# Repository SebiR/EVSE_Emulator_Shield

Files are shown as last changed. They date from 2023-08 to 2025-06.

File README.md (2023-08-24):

# EVSE Emulator Arduino Shield
An Arduino shield to emulate an EVSE (Electric Vehicle Supply Equipment), so basically it emulates a car charger

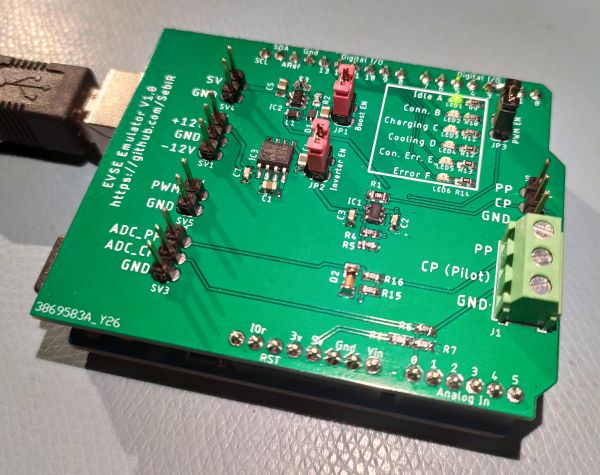
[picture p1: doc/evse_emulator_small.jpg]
EVSe Emulator Photo


## Features
* on-board charge pump and inverter for +12/-12V pilot signal
* Pilot level and PP level go to ADC channels
* Status LEDs

## Firmware
The Firmware is still in progress. It will be documented once finished

### Known Issues
* ADC values are dependent from USB voltage

## Resources
https://www.goingelectric.de/wiki/Typ2-Signalisierung-und-Steckercodierung/

## Disclaimer
This project was created to test an EV emulator. This project is not intended to be used in an actual Wallbox. 
There are no safety features and neither the firmware nor the hardware are created with robustness and safety in mind.
Although the state machine would be able to work as a full EVSE.

Use at your own risk. Im not liable for burning houses, cars or pants.

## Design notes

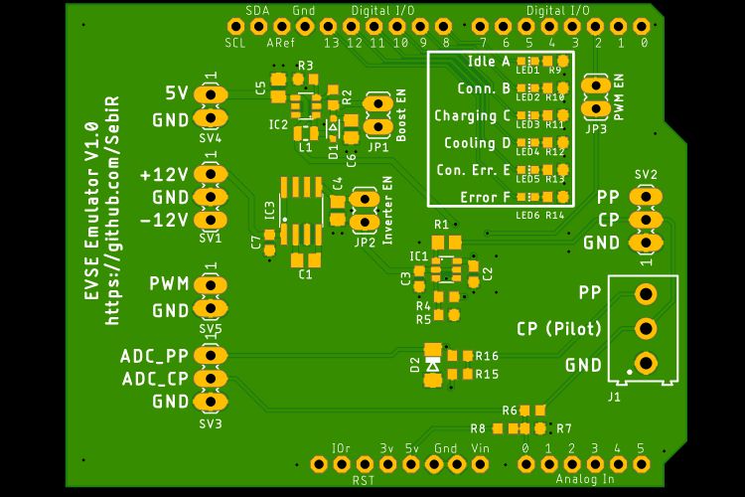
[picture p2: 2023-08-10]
doc/EVSE_Arduino_Shield_small.jpg

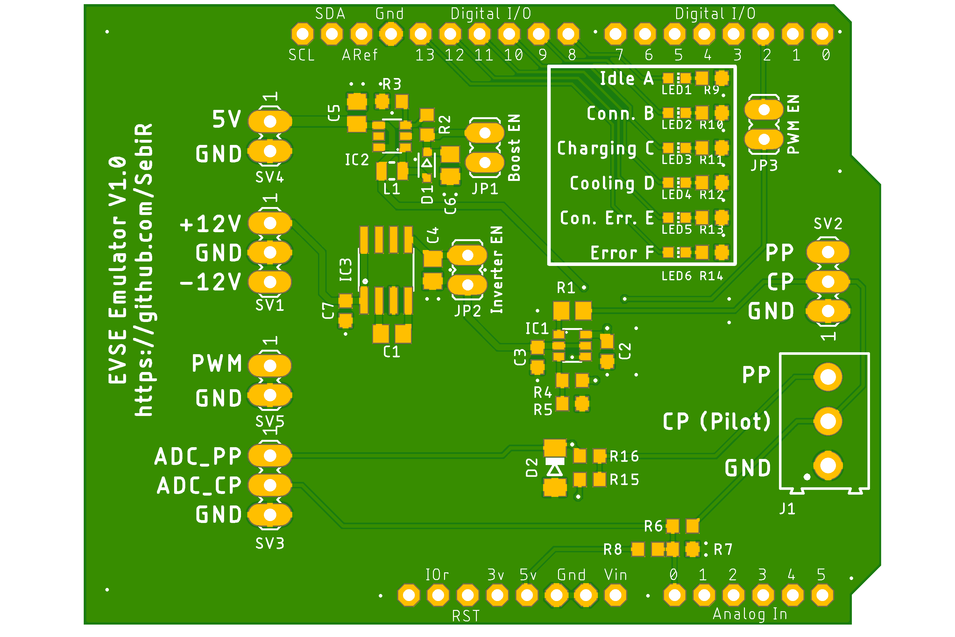
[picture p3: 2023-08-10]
doc/EVSE_Arduino_Shield.png

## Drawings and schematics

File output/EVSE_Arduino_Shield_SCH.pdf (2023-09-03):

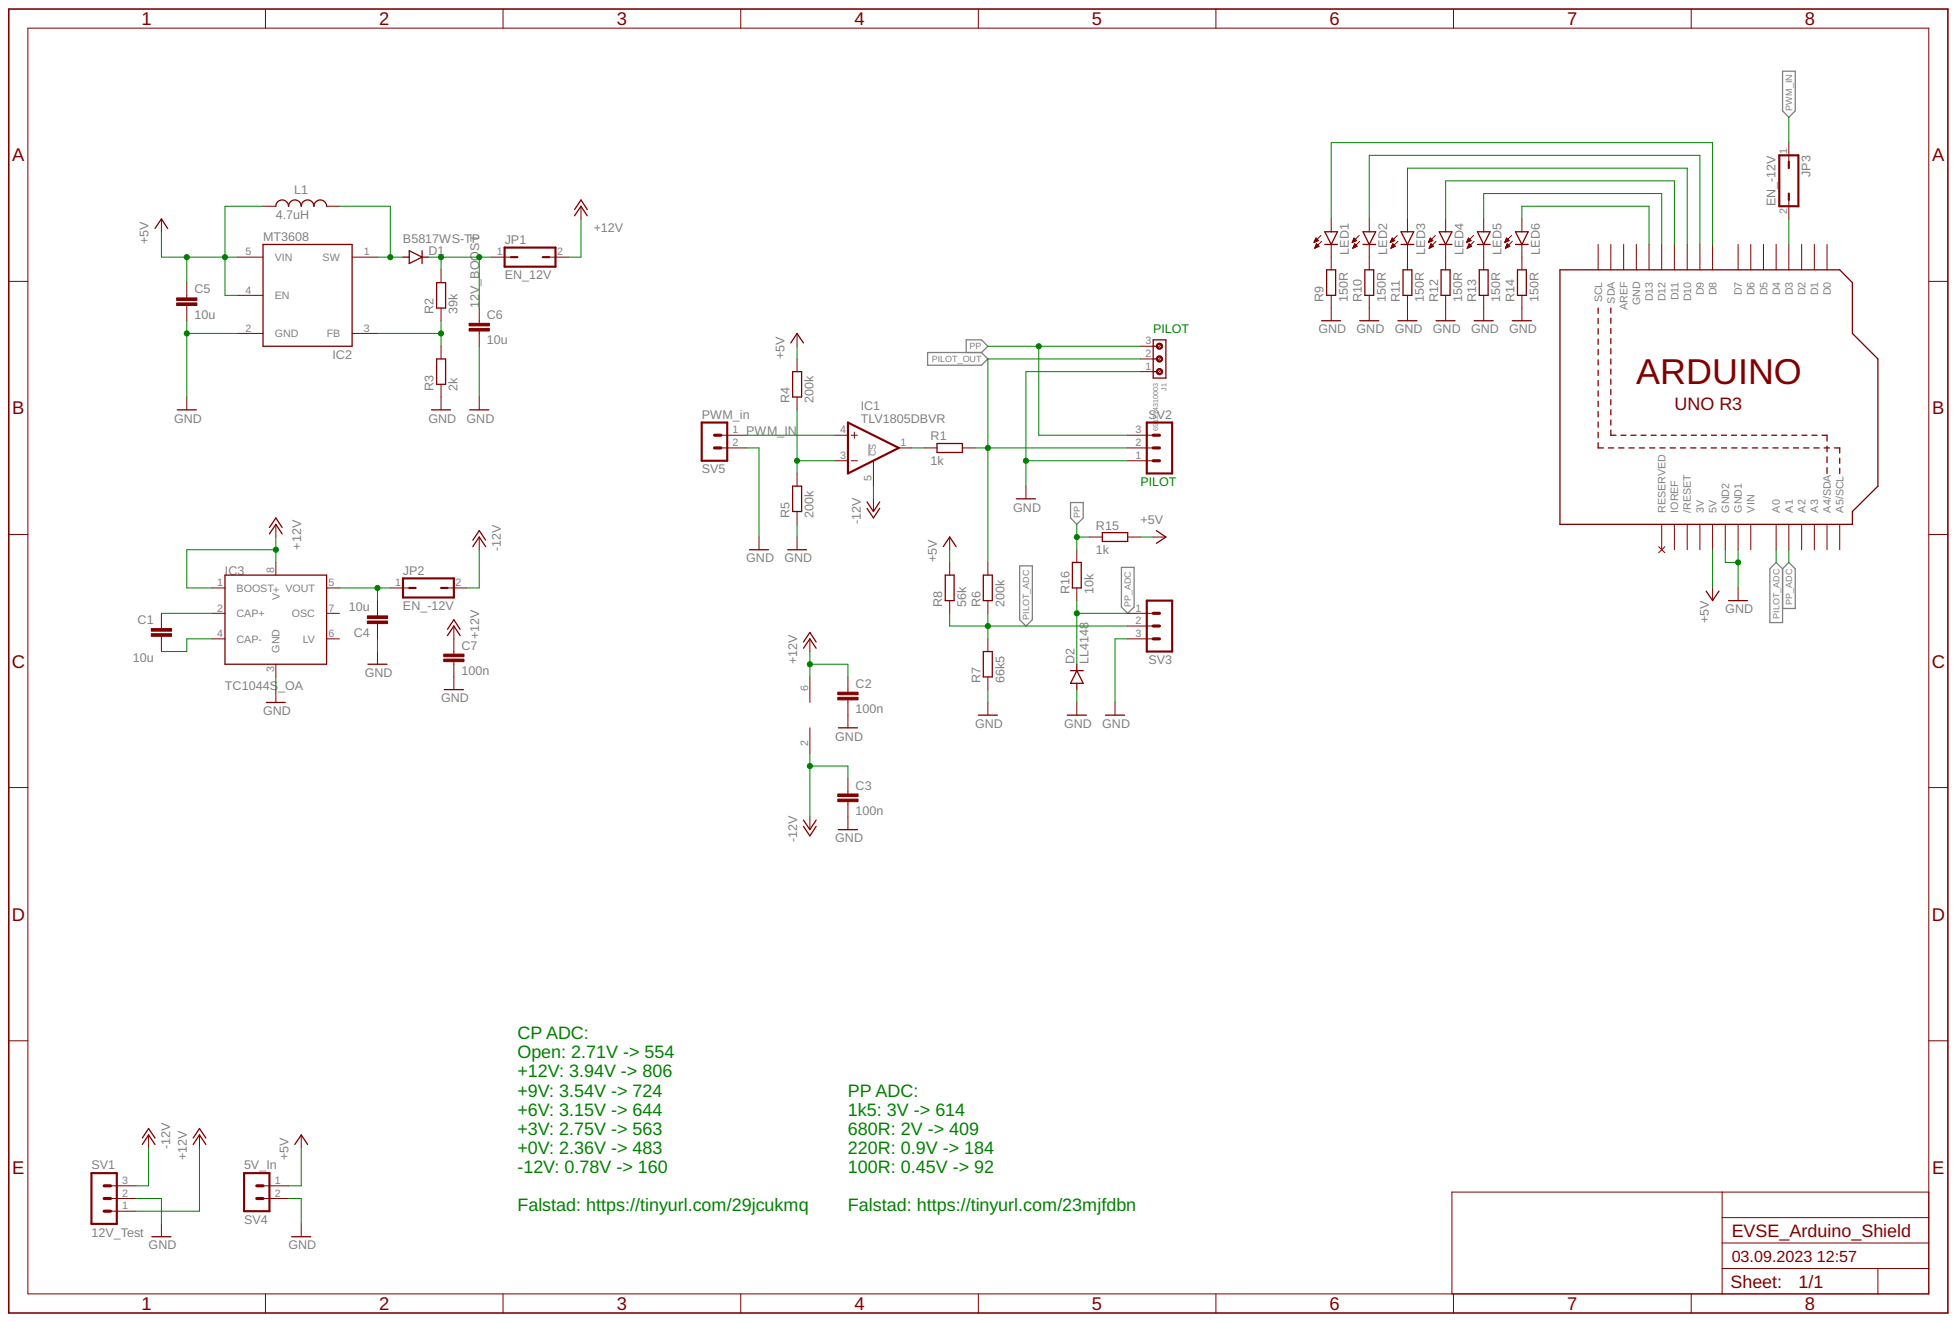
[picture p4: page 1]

GND GND GND

Falstad: https://tinyurl.com/29jcukmq

Falstad: https://tinyurl.com/23mjfdbn

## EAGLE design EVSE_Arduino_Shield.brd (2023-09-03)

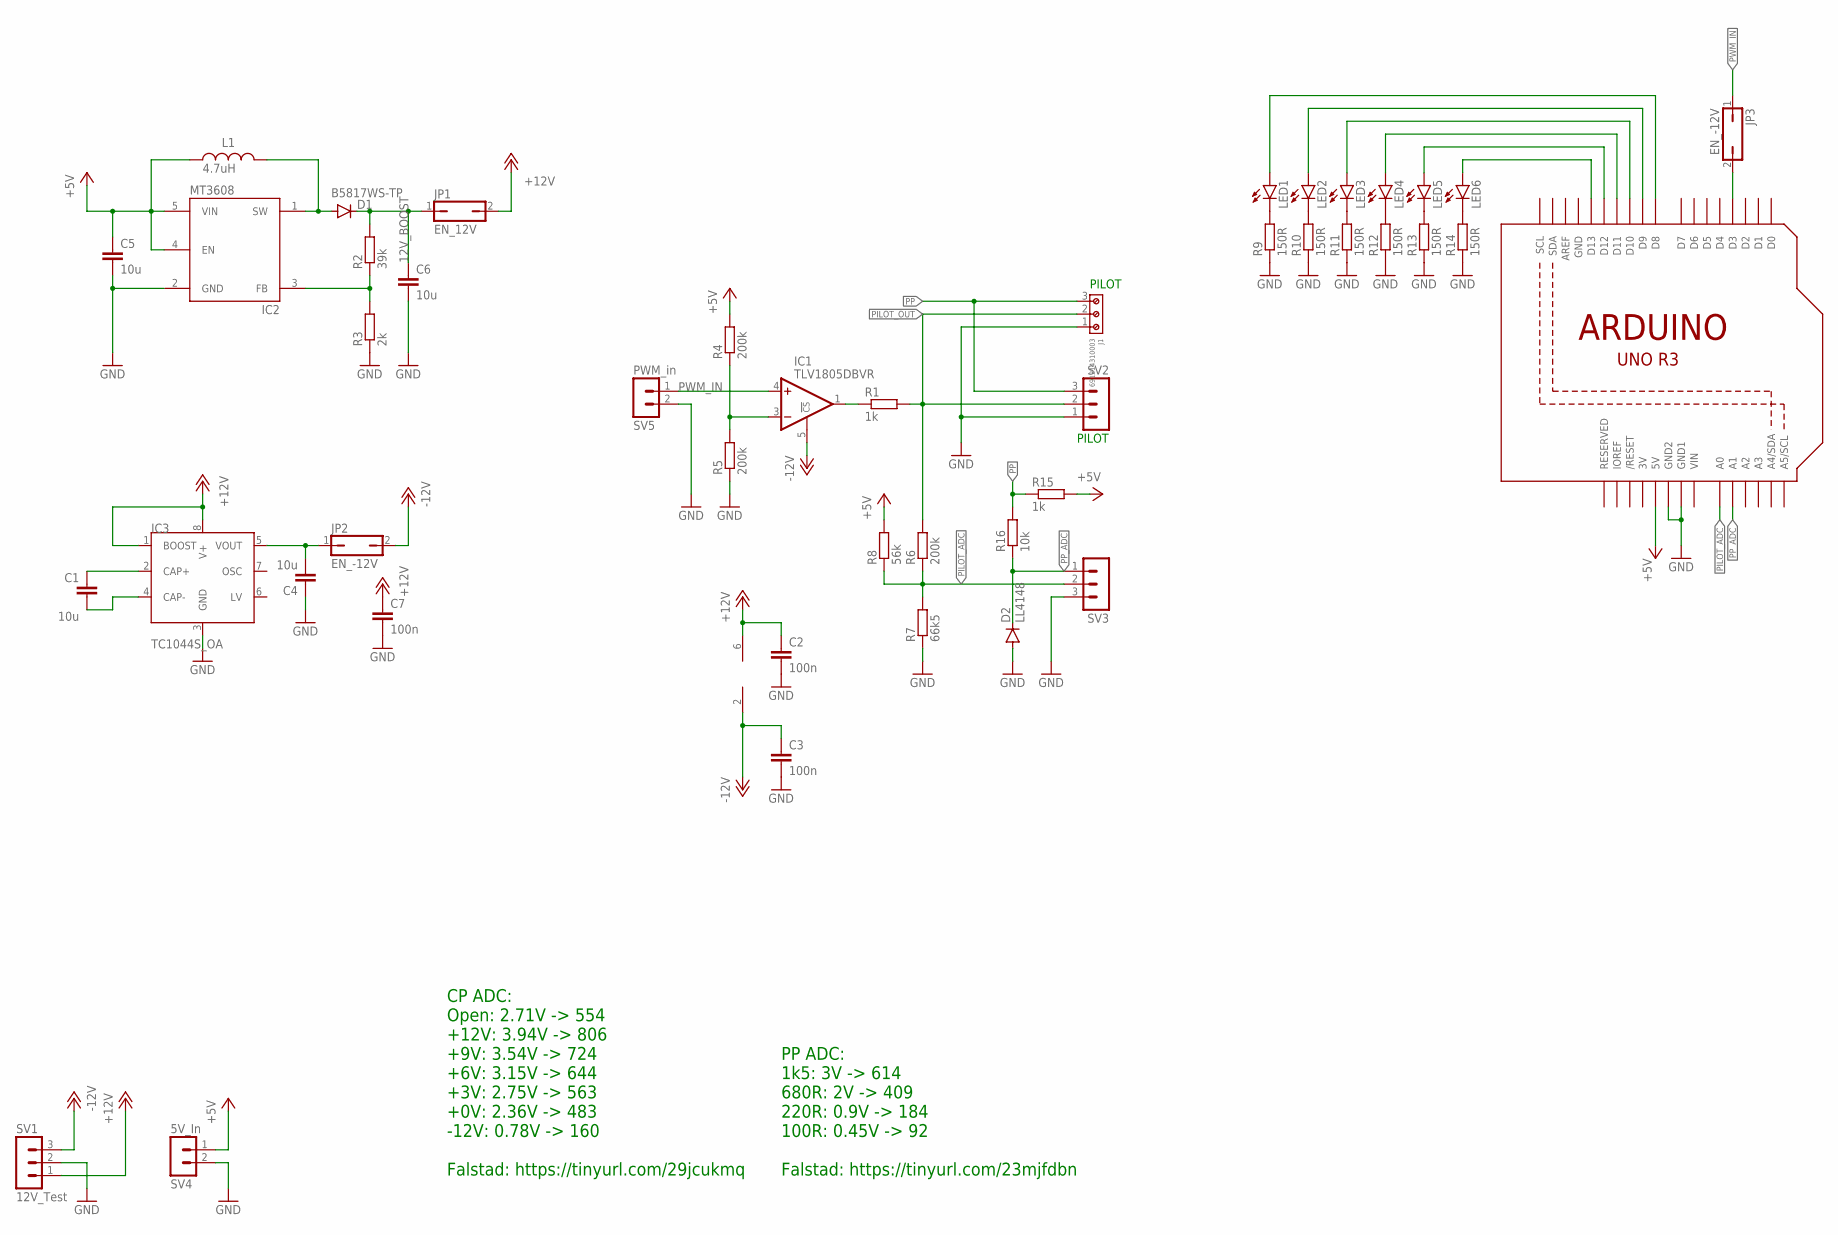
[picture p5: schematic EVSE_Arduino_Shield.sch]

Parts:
C1, C4, C5, C6: 10u; C0805
C2, C3, C7: 100n; C0603
D1: B5817WS-TP; SOD323-R
D2: LL4148; SOD80C
IC1: TLV1805DBVR; SOT23-6
IC2: MT3608; SOT23-6
IC3: TC1044S_OA; SO08
J1: 691214310003
JP1: EN_12V; JP1
JP2, JP3: EN_-12V; JP1
L1: 4.7uH; WE-PMI_0805_H1
LED1, LED2, LED3, LED4, LED5, LED6: LEDCHIP-LED0603; CHIP-LED0603
R1: 1k; R0805
R2: 39k; R0603
R3: 2k; R0603
R4, R5, R6: 200k; R0603
R7: 66k5; R0603
R8: 56k; R0603
R9, R10, R11, R12, R13, R14: 150R; R0603
R15: 1k; R0603
R16: 10k; R0603
SV1: 12V_Test; MA03-1
SV2, SV3: MA03-1
SV4: 5V_In; MA02-1
SV5: PWM_in; MA02-1
U2: ARDUINOR3-DIMENSION; ARDUINOR3

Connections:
3V: U2.3V
12V_BOOST: C6.1, D1.C, JP1.1, R2.2
+5V: C5.1, IC2.4 (EN), IC2.5 (VIN), L1.1, R4.2, R8.2, R15.2, SV4.1, U2.5V
+12V: C2.1, C7.1, IC1.6 (V+), IC3.1 (BOOST), IC3.8 (V+), JP1.2, SV1.1
-12V: C3.1, IC1.2 (V-), IC1.5 (!CS), JP2.2, SV1.3
BOOST_SW: D1.A, IC2.1 (SW), L1.2
GND: C2.2, C3.2, C4.1, C5.2, C6.2, C7.2, D2.A, IC2.2 (GND), IC3.3 (GND), J1.1, R3.1, R5.1, R7.1, R9.1, R10.1, R11.1, R12.1, R13.1, R14.1, SV1.2, SV2.1, SV3.3, SV4.2, SV5.2, U2.GND, U2.GND1, U2.GND2
unnamed: LED1.C, R9.2
unnamed: LED2.C, R10.2
unnamed: IC2.3 (FB), R2.1, R3.2
unnamed: IC1.1 (OUT), R1.1
unnamed: JP3.2, U2.D3
unnamed: LED3.C, R11.2
unnamed: C4.2, IC3.5 (VOUT), JP2.1
unnamed: IC1.3 (-IN), R4.1, R5.2
unnamed: LED4.C, R12.2
unnamed: LED5.C, R13.2
unnamed: C1.1, IC3.2 (CAP+)
unnamed: C1.2, IC3.4 (CAP-)
unnamed: LED6.C, R14.2
unnamed: LED6.A, U2.D13
unnamed: LED5.A, U2.D12
unnamed: LED4.A, U2.D11
unnamed: LED3.A, U2.D10
unnamed: LED2.A, U2.D9
unnamed: LED1.A, U2.D8
PILOT_ADC: R6.1, R7.2, R8.1, SV3.2, U2.A0
PILOT_OUT: J1.2, R1.2, R6.2, SV2.2
PP: J1.3, R15.1, R16.2, SV2.3
PP_ADC: D2.C, R16.1, SV3.1, U2.A1
PWM_IN: IC1.4 (+IN), JP3.1, SV5.1
VIN: U2.VIN

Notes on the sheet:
PILOT
CP ADC: Open: 2.71V -> 554 +12V: 3.94V -> 806 +9V: 3.54V -> 724 +6V: 3.15V -> 644 +3V: 2.75V -> 563 +0V: 2.36V -> 483 -12V: 0.78V -> 160 Falstad: https://tinyurl.com/29jcukmq
PP ADC: 1k5: 3V -> 614 680R: 2V -> 409 220R: 0.9V -> 184 100R: 0.45V -> 92 Falstad: https://tinyurl.com/23mjfdbn

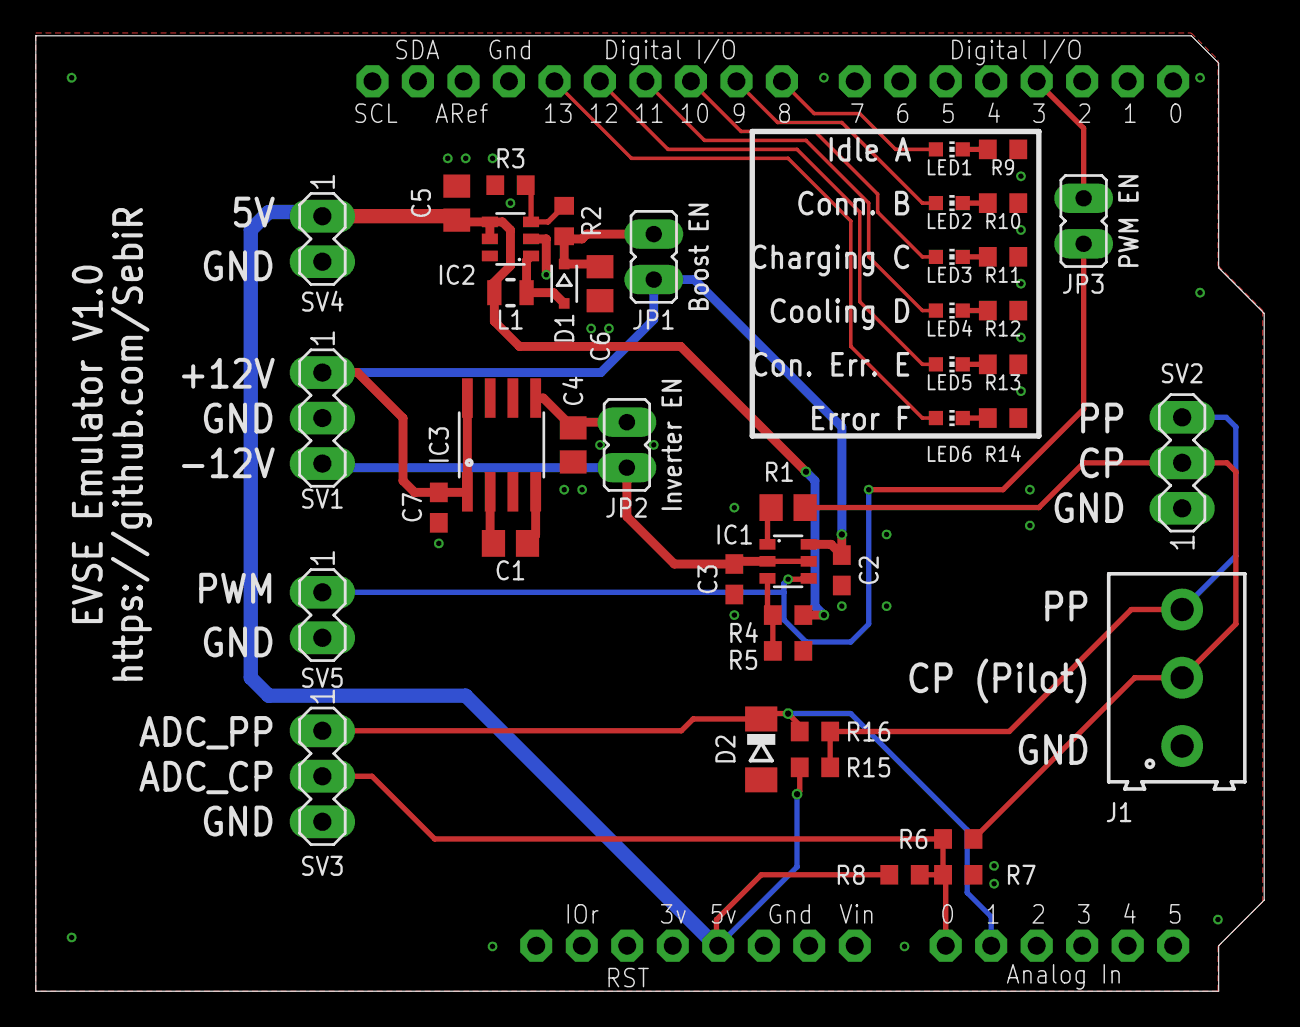
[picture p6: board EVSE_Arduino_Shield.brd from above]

Board: 2 copper layers, 68.6 x 53.3 mm, 45 parts (0 on the bottom side), 30 nets.

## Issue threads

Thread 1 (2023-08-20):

PWM is on wrong Pin

SebiR, 2023-08-20:
PWM output should be moved from D2 to D3. this is the OC2B output of Timer 2

https://docs.arduino.cc/tutorials/generic/secrets-of-arduino-pwm#using-the-atmega-pwm-registers-directly

Closed 2023-09-03.

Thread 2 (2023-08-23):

MT3608 has wrong pinout

SebiR, 2023-08-23:
Pin 6 is nc and Pin 5 is VIN, the part in the schematic has it the wrong way round

Closed 2023-09-03.

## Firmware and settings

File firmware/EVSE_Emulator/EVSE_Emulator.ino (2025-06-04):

#include "config.h"

volatile long pwm_adc_value = 0;
volatile int average_counter = 0;
volatile bool pilot_adc_flag = LOW;

int fsm_state = STATE_IDLE;

void setup() {

  // Debug Pin
  pinMode(7, OUTPUT);

  Serial.begin(115200);
  init_leds();

  Serial.println("EVSE Emulator 1.0");
}

void loop() {

  if (pilot_adc_flag) {

    float pilot_volt = mapfloat(pwm_adc_value / average_counter, 160, 819, -12.0, 12.0);
    Serial.println("Pilot Voltage:" + String(pilot_volt) + " [raw: " + String(pwm_adc_value / average_counter) + "]");
    fsm_state = volt2state(pilot_volt);

    pwm_adc_value = 0;
    average_counter = 0;
    pilot_adc_flag = LOW;  // Reset flag
  }

  set_statusleds(fsm_state);

  switch (fsm_state) {
    case STATE_IDLE:
      Serial.println("FSM: IDLE");
      set_pwm(PWM_ALWAYS_ON);
      break;
    case STATE_CONNECTED:
      Serial.println("FSM: CONNECTED");
      delay(500);
      set_pwm(PWM_30A);
      break;
    case STATE_CHARGING:
      Serial.println("FSM: CHARGING");
      set_pwm(PWM_30A);
      break;
    case STATE_COOLING:
      Serial.println("FSM: COOLING");
      set_pwm(PWM_30A);
      break;
    case STATE_CONERROR:
      Serial.println("FSM: CONNECTION ERROR");
      set_pwm(PWM_ALWAYS_ON);
      break;
    case STATE_ERROR:
      Serial.println("FSM: ERROR");
      set_pwm(PWM_ALWAYS_ON);
      //fsm_state = STATE_IDLE;
      break;
    default:
      Serial.println("FSM: We should not be here...");
      set_pwm(PWM_ALWAYS_ON);
      //fsm_state = STATE_ERROR;
      break;
  }

  delay(500);
}


// Timer Compare A Interrupt vector, called with rising edge of PWM
// Used for ADC measurement during high cycle
ISR(TIMER2_COMPA_vect) {  // called by timer2

  delayMicroseconds(50);  // wait for value to stabilize

  // Check if we need to acquire more samples (Flag not set and not enough samples)
  if (!pilot_adc_flag && (average_counter < PILOT_ADC_AVG)) {
    digitalWrite(7, HIGH);
    pwm_adc_value += analogRead(ADC_PWM);  //approx. 110us. But capuring should be a lot faster
    average_counter++;
    // ToDo: Just trigger a single conversion here, check for everything else in main
    digitalWrite(7, LOW);
  } else {
    // Signal that we've captured enough samples
    pilot_adc_flag = HIGH;
  }
}

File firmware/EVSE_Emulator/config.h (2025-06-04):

#define LED_IDLE 8
#define LED_CONN 9
#define LED_CHRG 10
#define LED_COOL 11
#define LED_CERR 12
#define LED_ERR 13

#define ADC_PWM 0
#define ADC_PP 1

#define VOLT_IDLE 12.0
#define VOLT_CONNECTED 9.0
#define VOLT_CHARGING 6.0
#define VOLT_COOLING 3.0
#define VOLT_CONERROR 0.0
#define VOLT_ERROR -12.0
#define VOLT_WINDOW 1.0 // Tolerance for voltage

#define PILOT_ADC_AVG 50 //Number of cycles for pilot adc signal averaging

void set_statusleds(int status);
void init_leds(void);
void set_pwm(int width);
int volt2state(float volt);
float mapfloat(long x, long in_min, long in_max, long out_min, long out_max);

enum STATE {
  STATE_IDLE = 0x01,
  STATE_CONNECTED = 0x02,
  STATE_CHARGING = 0x04,
  STATE_COOLING = 0x08,
  STATE_CONERROR = 0x10,
  STATE_ERROR = 0x20
};

enum PWM_MODE {
  PWM_ALWAYS_ON = 249,  // 100% PWM for negotiation
  PWM_30A = 125,         // 50% PWM equals 30A
  PWM_16A = 65,         // 27% PWM equals 16A
  PWM_10A = 40,         // 16% PWM equals 10A
  PWM_6A = 25         // 10% PWM
};

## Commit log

2023-08-18 * Fixed missing values of R2, R3, C5, C1, C6, C4
    [EVSE_Arduino_Shield.brd, EVSE_Arduino_Shield.sch]
2023-08-18 * Created new Schematic Output with added component values
2023-08-19 * Added very first stage of firmware (Just a basic LED test. Nothing more)
2023-08-20 * Started abstraction on FW. Still only blinking LEDs.
2023-08-20 Added PWM output control functions and added (empty) interrupt function for ADC measurement when PWM output is on high cycle
2023-08-20 Started Pilot ADC logic and voltage to STATE conversion
2023-08-21 * Added Pilot ADC function incl. averaging * Added PWM status according to Connection State (fixed 50% for now)
    [EVSE_Emulator.ino, config.h]
2023-08-24 Started on PP adc functions. Not much yet. Hardware is confirmed to work with minor issues.
    [EVSE_Emulator.ino]
2023-08-24 *updated documentation * changed ADC raw values for CP
2023-09-03 * Cleaned Code a bit * Fixed Issue #1 - PWM is now on D3 * Fixed Issue #2 . MT3608 has the correct pin out now * Re-generated GERBER and SCH
    [EVSE_Arduino_Shield.brd, EVSE_Arduino_Shield.sch]
2025-06-04 * Updated current output struct to include different max. output currents (no further use yet)

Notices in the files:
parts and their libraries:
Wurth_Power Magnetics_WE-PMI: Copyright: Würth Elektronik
